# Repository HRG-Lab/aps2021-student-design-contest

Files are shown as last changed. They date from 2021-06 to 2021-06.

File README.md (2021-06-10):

# 2021 IEEE APS/URSI Student Design Contest

This repository contains the Huff Research Group's submission to the [2021 APS Student Design Contest](https://www.ieeeaps.org/education/student-design-contest), Project Artemis. The goal of this project is to demonstrate a software-defined radio (SDR) phased array architecture that performs direction of arrival (DoA) and beamforming (BF). The system will be composed of the KerberosSDR, a 4-channel coherent radio, and use a modified version of the KerberosSDR demo software to perform MUSIC spectral estimation. The focus will be building an educational toolkit that can be utilized to teach beamforming and DoA, comparing analog and digital techniques as well as hybrid analog-digital architectures.

## Motivation and Application

Radio telemetry and direction-finding methods have enabled researchers, practitioners, and citizen scientists in agriculture and biological sciences for decades. These tools are commonly used in data collection on diverse animal populations, such as tracking migratory behavior and monitoring threatened species. Coalescing this data with geotags allows scientists to infer the health of the environment and habitats where these animals reside. Recently, such techniques have been deployed to track the invasive species, _Vespa mandarinia_ (Asian giant hornet) and _Lycorma delicatula_ (spotted lanternfly), and study their impact on native ecosystems. _V. mandarinia_ can rapidly destroy entire honey bee colonies, and _L. delicatula_ can cause huge economic damage to farming and lumber industries.

The goal of Project Artemis is to design and build an extensible invasive species tracking system that utilizes an antenna array with an SDR to perform real-time DoA. Additionally, we view Artemis as a low-cost approach that lowers-the-barrier-to-entry for educators and citizen scientists to engage in the growing fields of antennas, electromagnetics, signal processing, and arrays.

## System Architecture

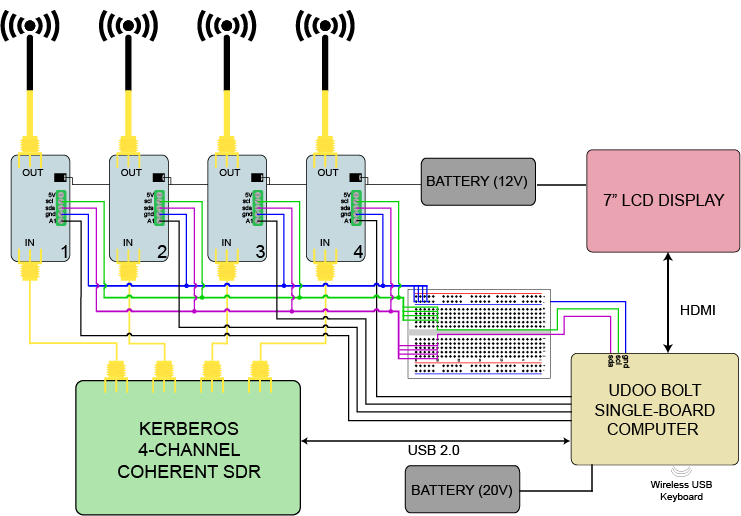
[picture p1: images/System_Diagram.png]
System Diagram


Above is a top-level diagram of Project Artemis detailing the interconnection between various components. The system consists of an easy-to-use software applet built-upon the KerberosSDR  project as well as custom-built, reconfigurable hardware components such as the tunable antenna elements and phase-shifter boards for hybrid beamforming. Towards the intended goal of supporting field-tracking, we have included a small display for real-time visualization and have designed the entire system to be collapsible in a ruggedized suitcase.

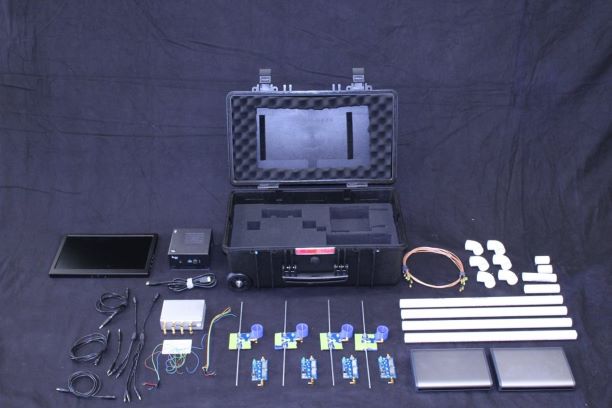
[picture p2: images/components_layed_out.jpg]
Components Layout

 
This shows all of the components to Artemis layed out on a table. This GitHub repository contains all of our design files as well as the source code to Artemis, and the end of this report includes the Bill of Materials. The subsections that follow describe in detail the hardware and software components.

## Artemis Software

The Artemis Software toolkit is a forked version of the KerberosSDR example toolkit, tailored for the purpose of easing usage for end-users.

## Analog Components

Fill in with information on the analog design files.

## Jupyter Teaching Notebooks

Fill in description of Jupyter notebooks to teach array processing.

## References

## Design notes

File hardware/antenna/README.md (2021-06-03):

# Antenna Design

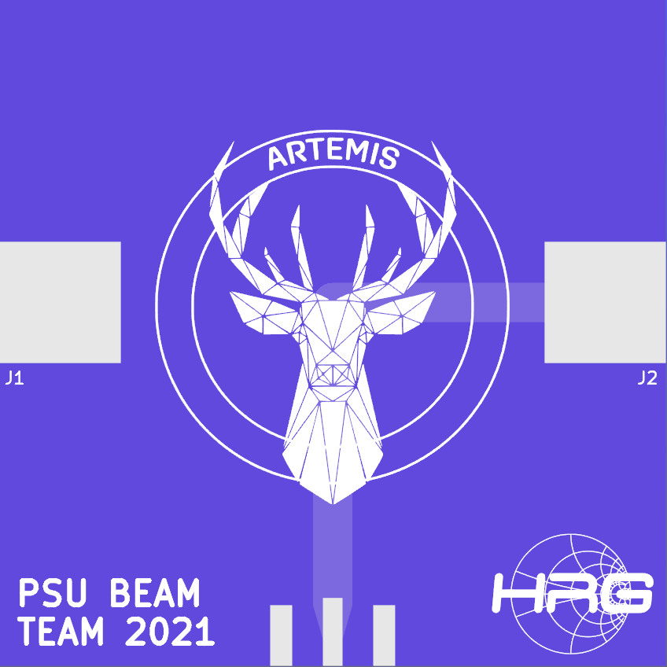
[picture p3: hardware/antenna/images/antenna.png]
Antenna


These are the production files for the antenna. J1 and J2 are each terminal
blocks which hold a conductor (eg. copper wire). When finally assembled, this
creates a dipole antenna.

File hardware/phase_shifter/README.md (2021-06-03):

# Phase Shifter Modules

These modules are designed to be individually addressable fully contained phase
shifters with a full 360 degree range. This folder contains all design files.

## Schematic

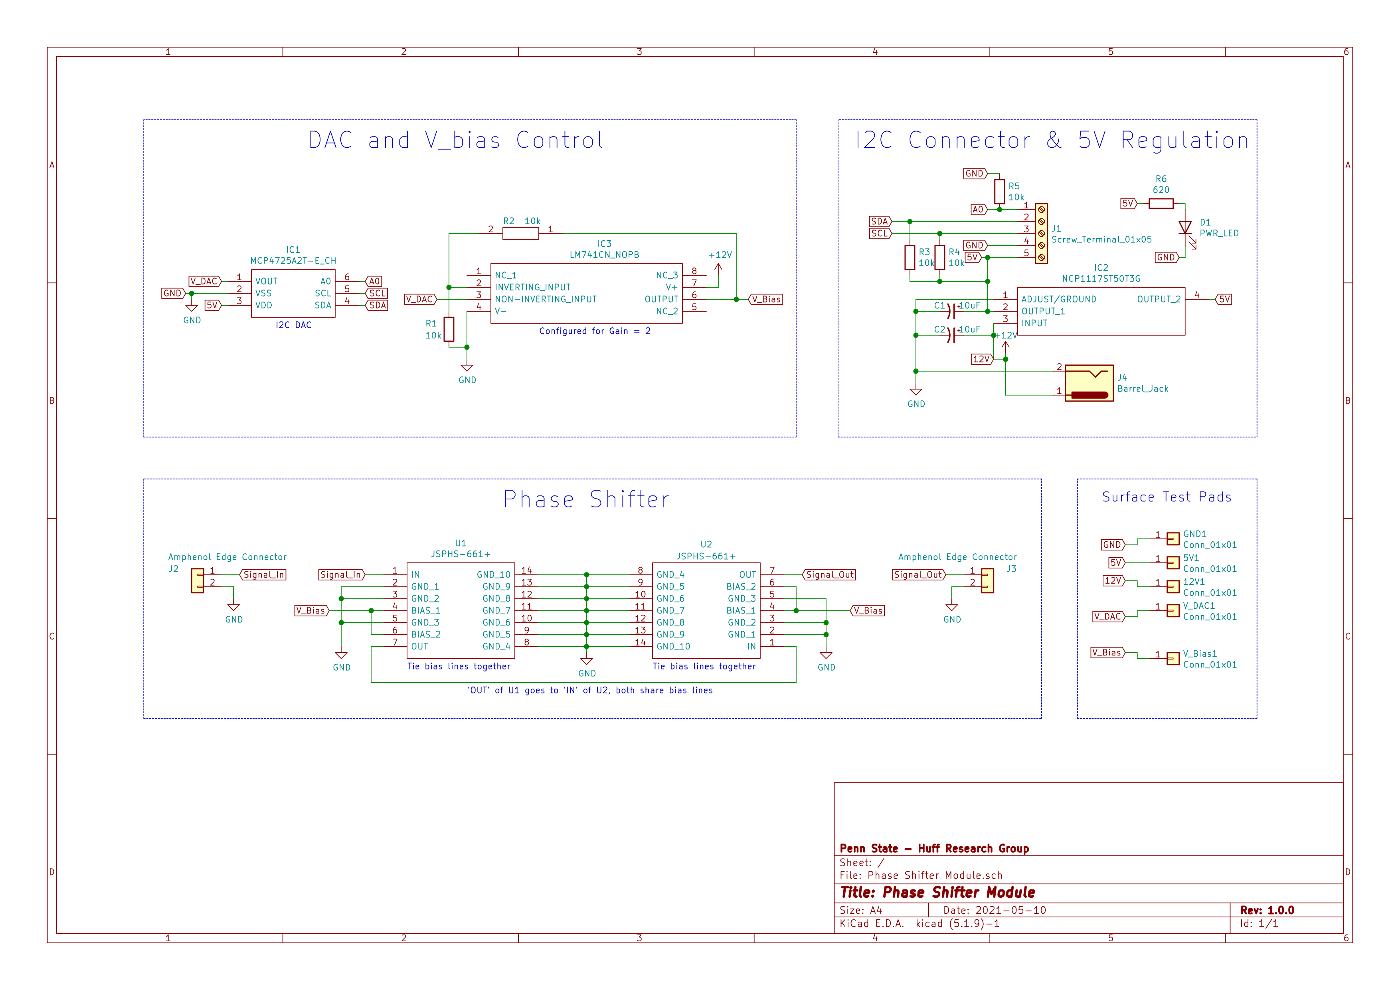
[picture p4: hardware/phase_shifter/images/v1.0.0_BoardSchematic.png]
KiCad Phase Shifter Schematic


## Bill of Materials

| Ref | Value | Footprint |
|---|---|---|
| 5V1 | Conn_01x01 | Phase Shifter Module:TestPad_Medium |
| 12V1 | Conn_01x01 | Phase Shifter Module:TestPad_Medium |
| C1 | 10uF | Capacitor_SMD:C_0805_2012Metric |
| C2 | 10uF | Capacitor_SMD:C_0805_2012Metric |
| D1 | PWR_LED | LED_SMD:LED_0805_2012Metric |
| GND1 | Conn_01x01 | Phase Shifter Module:TestPad_Medium |
| IC1 | MCP4725A2T-E_CH | Package_TO_SOT_SMD:SOT-23-6_Handsoldering |
| IC2 | NCP1117ST50T3G | NCP1117ST50T3G:SOT230P700X180-4N |
| IC3 | LM741CN_NOPB | Package_SO:SOP-8_3.9x4.9mm_P1.27mm |
| J1 | Screw_Terminal_01x05 | TerminalBlock_TE-Connectivity:TerminalBlock_TE_282834-5_1x05_P2.54mm_Horizontal |
| J2 | Amphenol Edge Connector | Amphenol Edge:Amphenol_132255_Edge |
| J3 | Amphenol Edge Connector | Amphenol Edge:Amphenol_132255_Edge |
| J4 | Barrel_Jack | Connector_BarrelJack:BarrelJack_CUI_PJ-063AH_Horizontal |
| R1 | 10k | Resistor_SMD:R_0805_2012Metric |
| R2 | 10k | Resistor_SMD:R_0805_2012Metric |
| R3 | 10k | Resistor_SMD:R_0805_2012Metric |
| R4 | 10k | Resistor_SMD:R_0805_2012Metric |
| R5 | 10k | Resistor_SMD:R_0805_2012Metric |
| R6 | 620 | Resistor_SMD:R_0805_2012Metric |
| U1 | JSPHS-661+ | SamacSys_Parts:JSPHS661 |
| U2 | JSPHS-661+ | SamacSys_Parts:JSPHS661 |
| V_Bias1 | Conn_01x01 | Phase Shifter Module:TestPad_Medium |
| V_DAC1  | Conn_01x01 | Phase Shifter Module:TestPad_Medium |

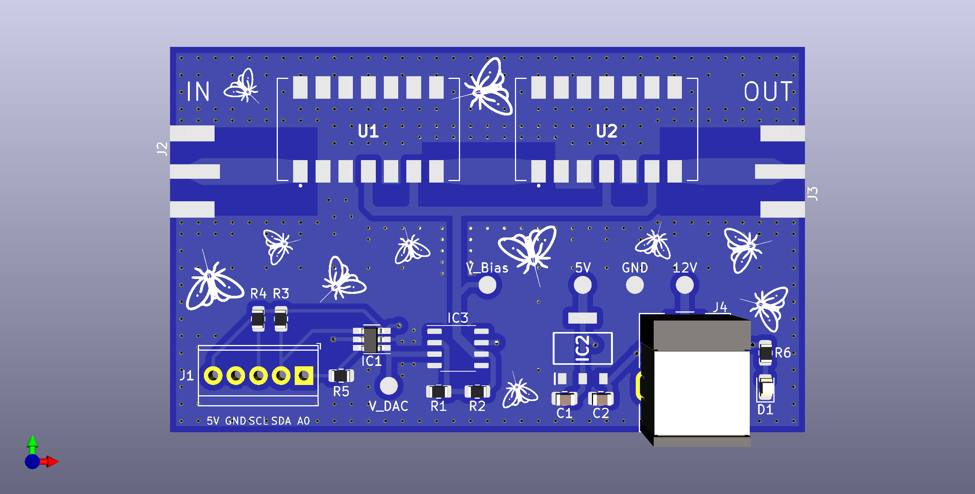
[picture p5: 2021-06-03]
hardware/phase_shifter/images/v1.0.0 3D Layout.png

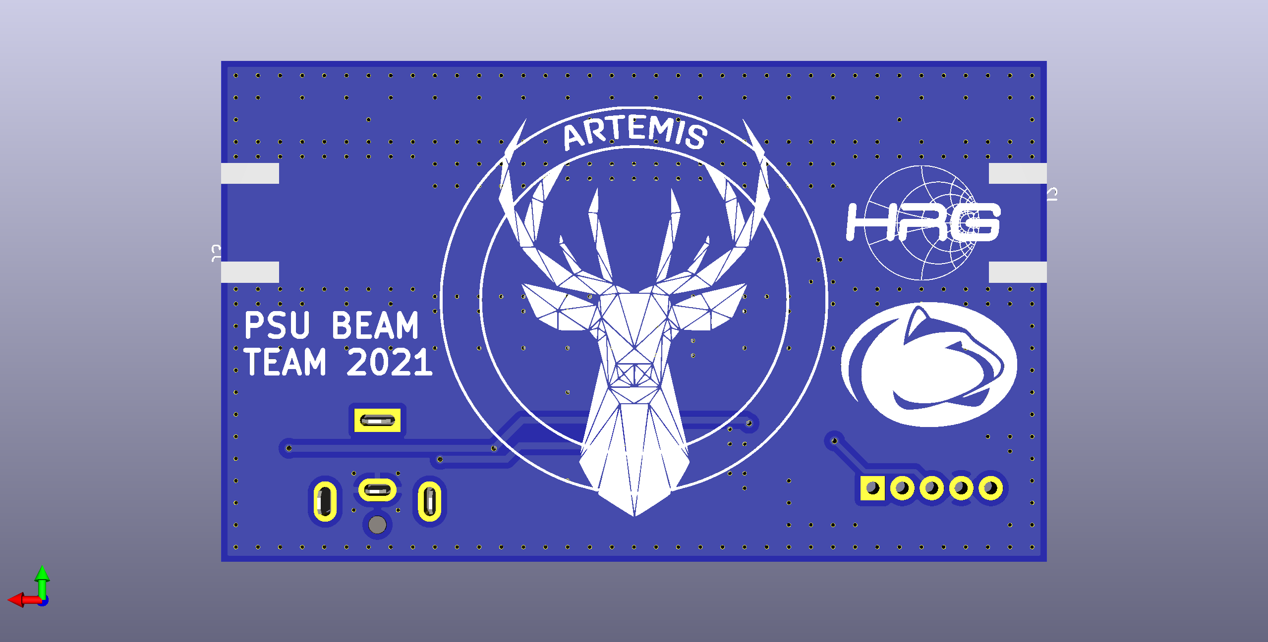
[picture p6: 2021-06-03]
hardware/phase_shifter/images/v1.0.0 3D Layout_Back.png

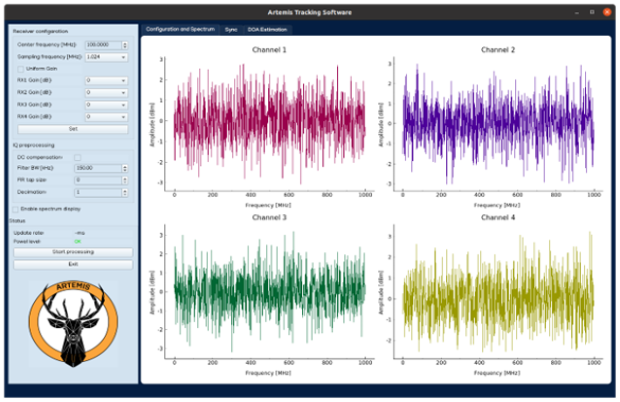
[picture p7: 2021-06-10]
images/Artemis_Spectrum.png

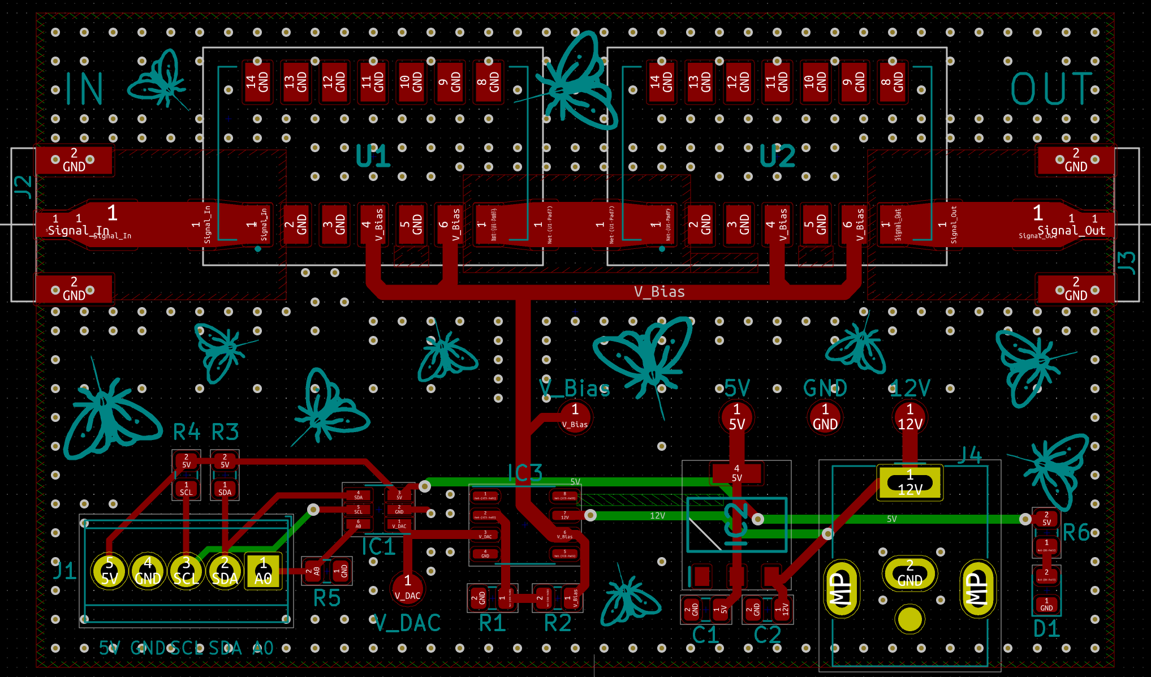
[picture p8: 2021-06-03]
hardware/phase_shifter/images/v1.0.0 Board Layout.png

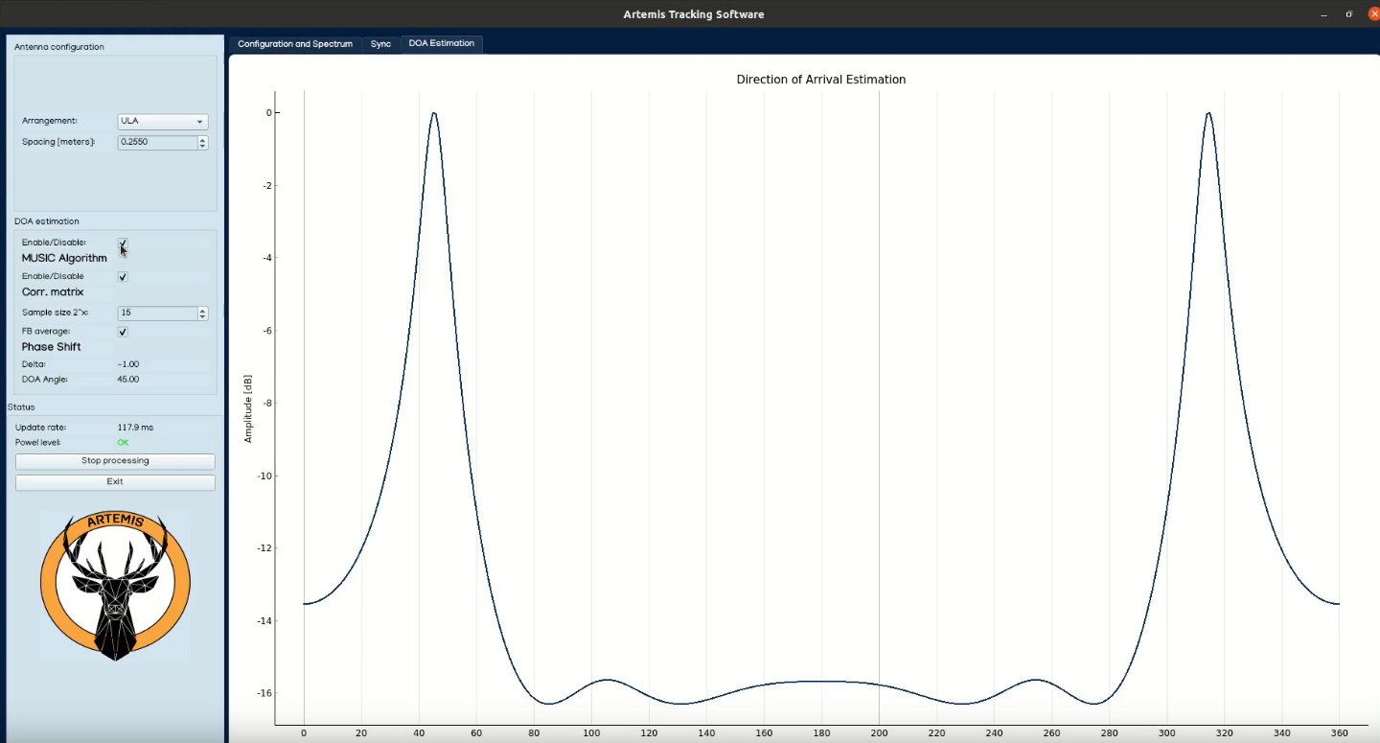
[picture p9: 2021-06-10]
images/hydra_doa.png

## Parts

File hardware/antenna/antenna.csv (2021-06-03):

Source: | /home/gaylybailey/Documents/HRG/sdr-df-bf/aps2021-sdc/aps2021-student-design-contest/hardware/antenna/antenna.sch
Date: | Thu 03 Jun 2021 05:16:01 PM EDT
Tool: | Eeschema 5.1.6+dfsg1-1
Component Count: | 3
Ref | Value | Footprint | Datasheet | Manufacturer | Vendor
J1 | Conn_01x01 | Antenna_Clamp_Adapter:Wire_Clamp | ~
J2 | Conn_01x01 | Antenna_Clamp_Adapter:Wire_Clamp | ~
J3 | Conn_01x02 | Antenna_Clamp_Adapter:Amphenol_132255_Edge | ~

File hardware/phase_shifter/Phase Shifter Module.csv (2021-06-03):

Source: | /home/gaylybailey/Documents/HRG/sdr-df-bf/aps2021-sdc/aps2021-student-design-contest/hardware/phase_shifter/Phase Shifter Module/Phase Shifter Module.sch
Date: | Thu 03 Jun 2021 03:17:47 PM EDT
Tool: | Eeschema 5.1.6+dfsg1-1
Component Count: | 23
Ref | Value | Footprint | Datasheet | Manufacturer | Vendor
5V1 | Conn_01x01 | Phase Shifter Module:TestPad_Medium | ~
12V1 | Conn_01x01 | Phase Shifter Module:TestPad_Medium | ~
C1 | 10uF | Capacitor_SMD:C_0805_2012Metric | ~
C2 | 10uF | Capacitor_SMD:C_0805_2012Metric | ~
D1 | PWR_LED | LED_SMD:LED_0805_2012Metric | ~
GND1 | Conn_01x01 | Phase Shifter Module:TestPad_Medium | ~
IC1 | MCP4725A2T-E_CH | Package_TO_SOT_SMD:SOT-23-6_Handsoldering | http://ww1.microchip.com/downloads/en/devicedoc/22039d.pdf
IC2 | NCP1117ST50T3G | NCP1117ST50T3G:SOT230P700X180-4N | http://www.onsemi.com/pub/Collateral/NCP1117-D.PDF
IC3 | LM741CN_NOPB | Package_SO:SOP-8_3.9x4.9mm_P1.27mm | https://www.ti.com/lit/ds/symlink/lmc6081.pdf?ts=1620626007476
J1 | Screw_Terminal_01x05 | TerminalBlock_TE-Connectivity:TerminalBlock_TE_282834-5_1x05_P2.54mm_Horizontal | ~
J2 | Amphenol Edge Connector | Amphenol Edge:Amphenol_132255_Edge | ~
J3 | Amphenol Edge Connector | Amphenol Edge:Amphenol_132255_Edge | ~
J4 | Barrel_Jack | Connector_BarrelJack:BarrelJack_CUI_PJ-063AH_Horizontal | ~
R1 | 10k | Resistor_SMD:R_0805_2012Metric | ~
R2 | 10k | Resistor_SMD:R_0805_2012Metric | ~
R3 | 10k | Resistor_SMD:R_0805_2012Metric | ~
R4 | 10k | Resistor_SMD:R_0805_2012Metric | ~
R5 | 10k | Resistor_SMD:R_0805_2012Metric | ~
R6 | 620 | Resistor_SMD:R_0805_2012Metric | ~
U1 | JSPHS-661+ | SamacSys_Parts:JSPHS661 | https://www.minicircuits.com/pdfs/JSPHS-661+.pdf
U2 | JSPHS-661+ | SamacSys_Parts:JSPHS661 | https://www.minicircuits.com/pdfs/JSPHS-661+.pdf
V_Bias1 | Conn_01x01 | Phase Shifter Module:TestPad_Medium | ~
V_DAC1 | Conn_01x01 | Phase Shifter Module:TestPad_Medium | ~

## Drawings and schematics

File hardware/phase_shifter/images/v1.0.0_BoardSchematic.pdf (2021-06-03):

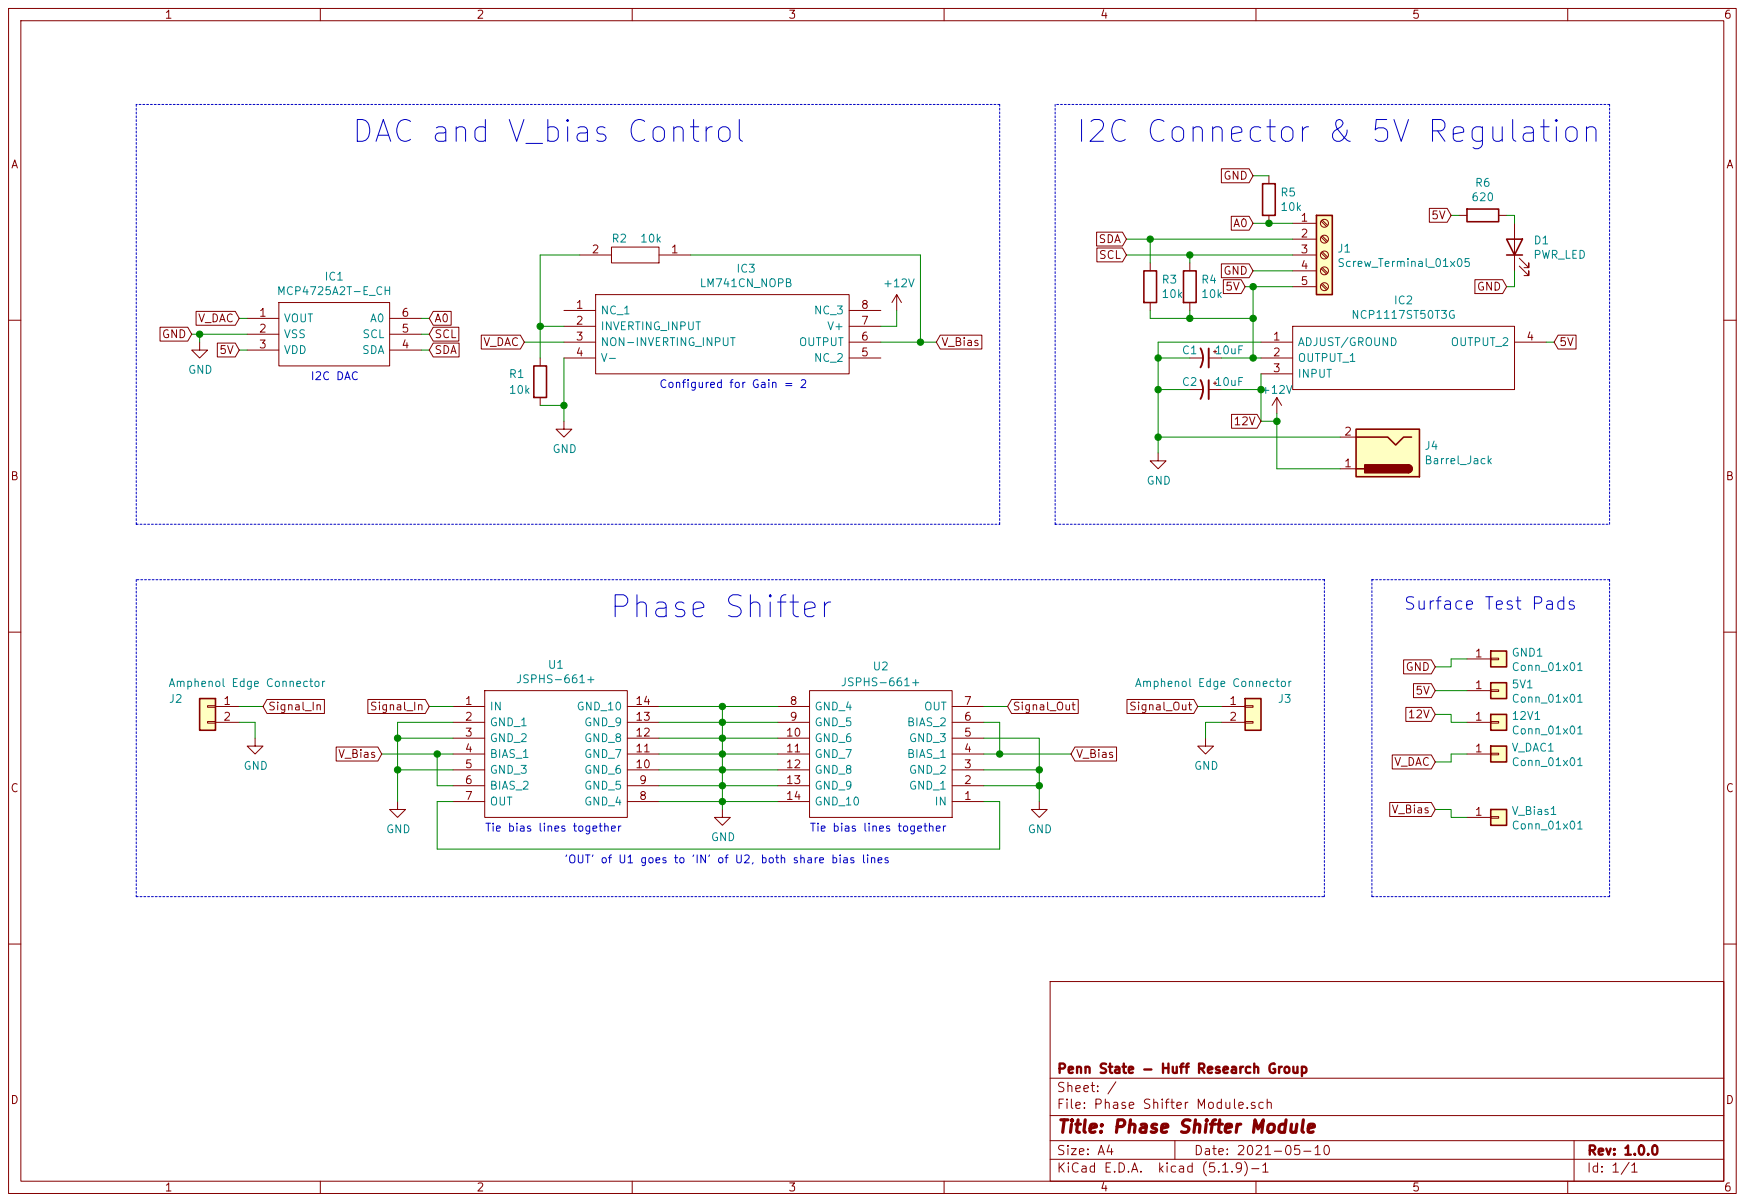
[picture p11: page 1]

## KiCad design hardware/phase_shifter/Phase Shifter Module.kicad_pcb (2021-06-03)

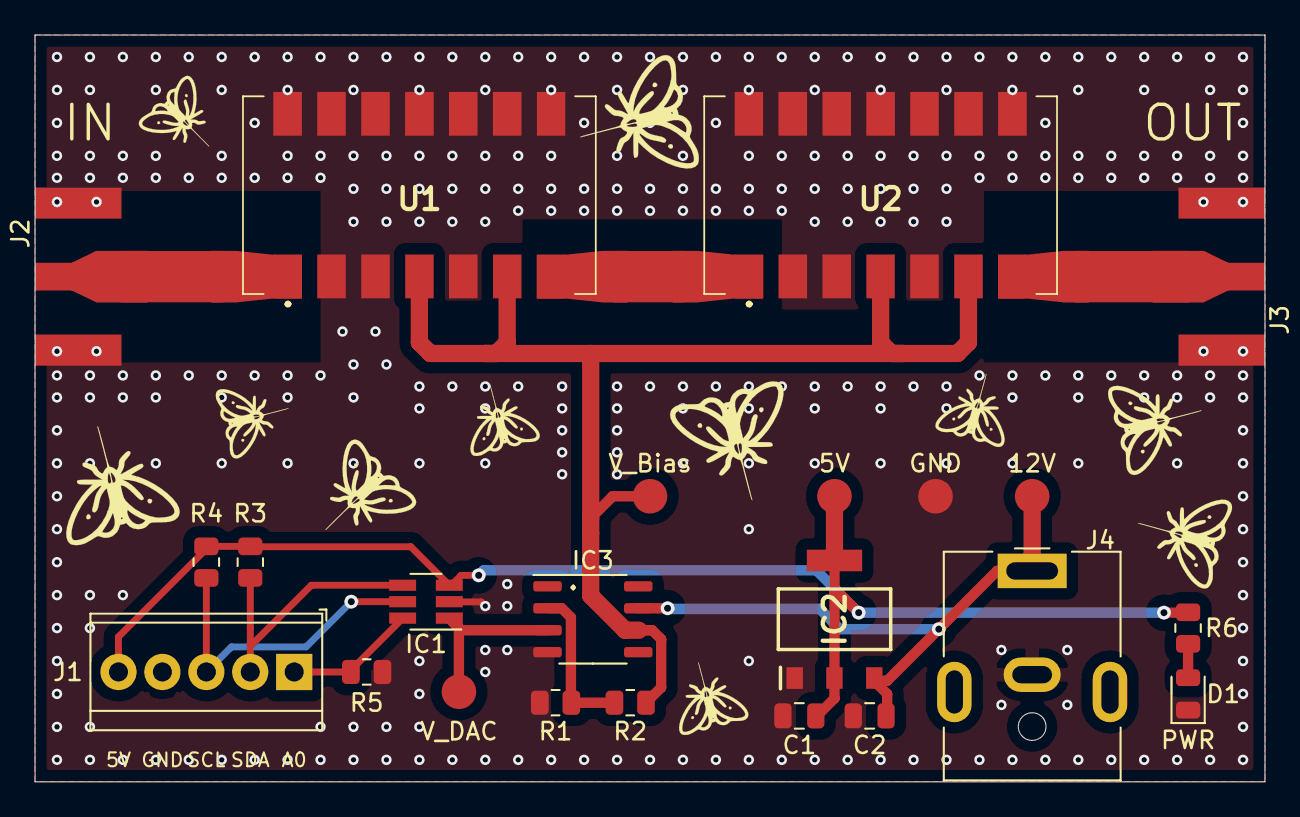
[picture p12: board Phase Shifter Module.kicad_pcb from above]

Board: 2 copper layers, 71.1 x 43.2 mm, 31 parts (0 on the bottom side), 13 nets.

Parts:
5V1, 12V1: Conn_01x01; TestPad_Medium
Artemis: LOGO; Artemis_Logo-Large
C1, C2: 10uF; C_0805_2012Metric
D1: PWR_LED; LED_0805_2012Metric
GND1: Conn_01x01; TestPad_Medium
IC1: MCP4725A2T-E_CH; SOT-23-6_Handsoldering
IC2: NCP1117ST50T3G; SOT230P700X180-4N
IC3: LM741CN_NOPB; SOP-8_3.9x4.9mm_P1.27mm
J1: Screw_Terminal_01x05; TerminalBlock_TE_282834-5_1x05_P2.54mm_Horizontal
J2, J3: Amphenol Edge Connector; Amphenol_132255_Edge
J4: Barrel_Jack; BarrelJack_CUI_PJ-063AH_Horizontal
PSU: LOGO; PSU_Logo
R1, R2, R3, R4, R5: 10k; R_0805_2012Metric
R6: 620; R_0805_2012Metric
Taper: Signal_Pad_to_2.97mm
Taper#2: Signal_Pad_to_2.97mm
Taper#3, Taper#4, Taper#5, Taper#6: 1.5mm_to_2.97mm
U1, U2: JSPHS-661+; JSPHS661
V_Bias1: Conn_01x01; TestPad_Medium
V_DAC1: Conn_01x01; TestPad_Medium

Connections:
5V: 5V1.1, C1.1, IC1.3, IC2.2, IC2.4, J1.5, R3.2, R4.2, R6.2
12V: 12V1.1, C2.1, IC2.3, IC3.7, J4.1
A0: IC1.6, J1.1, R5.2
GND: C1.2, C2.2, D1.1, GND1.1, IC1.2, IC2.1, IC3.4, J1.4, J2.2, J3.2, J4.2, R1.2, R5.1, U1.2, U1.3, U1.5, U1.8, U1.9, U1.10, U1.11, U1.12, U1.13, U1.14, U2.2, U2.3, U2.5, U2.8, U2.9, U2.10, U2.11, U2.12, U2.13, U2.14
unnamed: D1.2, R6.1
unnamed: IC3.2, R1.1, R2.2
unnamed: Taper#5.1, Taper#6.1, U1.7, U2.1
SCL: IC1.5, J1.3, R4.1
SDA: IC1.4, J1.2, R3.1
Signal_In: J2.1, Taper#2.1, Taper#3.1, U1.1
Signal_Out: J3.1, Taper.1, Taper#4.1, U2.7
V_Bias: IC3.6, R2.1, U1.4, U1.6, U2.4, U2.6, V_Bias1.1
V_DAC: IC1.1, IC3.3, V_DAC1.1

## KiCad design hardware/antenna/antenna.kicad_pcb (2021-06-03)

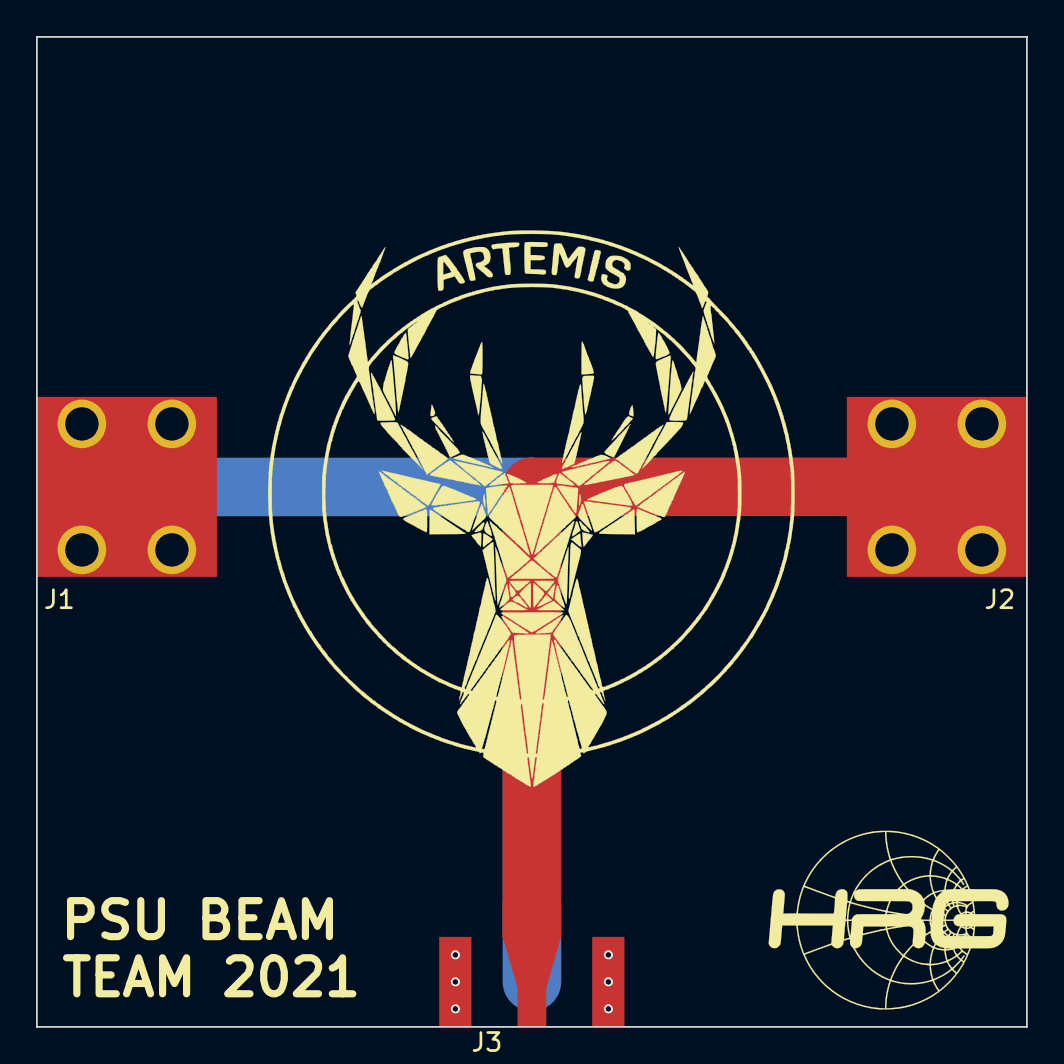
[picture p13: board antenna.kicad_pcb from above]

Board: 2 copper layers, 55.0 x 55.0 mm, 4 parts (0 on the bottom side), 2 nets.

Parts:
J1, J2: Conn_01x01; Wire_Clamp
J3: Conn_01x02; Amphenol_132255_Edge
uwT*****: Signal_Pad_to_3.25mm

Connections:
unnamed: J1.1, J3.2
unnamed: J2.1, J3.1, uwT*****.1

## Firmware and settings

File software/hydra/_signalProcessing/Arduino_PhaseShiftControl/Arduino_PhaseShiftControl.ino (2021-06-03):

/*
  Phase Shifter Module Control Software

  PSU BEAM Team 2021 - Rebecca DeSipio, Mike Shero, Ethan Tabler

  This program requires the Adafruit MCP4725 library to function.
*/

#include <Wire.h>
#include <Adafruit_MCP4725.h>

Adafruit_MCP4725 dac;

void setup() {
  // init digital pins
  pinMode(0, OUTPUT);
  pinMode(1, OUTPUT);
  pinMode(2, OUTPUT);
  pinMode(3, OUTPUT);
  
  // close existing connections before
  Serial.end();

  // initialize serial communication
  Serial.begin(9600);
  Serial.println("Serial connection initialized.");
  
  // This application uses the MCP4725(A2), not the Adafruit breakout board.
  // For the PSM's MCP4725A2 the address is 0x64 (default) or 0x65 (ADDR pin tied to VCC)
  // For MCP4725A0 the address is 0x60 or 0x61
  // For MCP4725A1 the address is 0x62 or 0x63 (Adafruit Breakout Board)
  dac.begin(0x65);

  // initialize A0 control pins and set all LOW
  pinMode(0, OUTPUT);
  pinMode(1, OUTPUT);
  pinMode(2, OUTPUT);
  pinMode(3, OUTPUT);
  for (int i = 0, i <= 3, i++) {
        digitalWrite(i, LOW);
  }
}

void loop() {
  // see if there's incoming serial data
  if (Serial.available() > 0) {
    // look for the next valid integer in the incoming serial stream
    int dacVal = Serial.parseInt();

    // look for the newline --> end of sent value
    if (Serial.read() == '\n') {
     
      //dac.setVoltage((dacVal), false);

      // because there are 4 phase shifters (1 per channel), we must apply
      // the appropriate delta values to each module
      for (int i = 0, i <= 3, i++) {
        // apply delta value --> 0, 1*d, 2*d, 3*d
        digitalWrite(i, HIGH);
        delay(10);
        dac.setVoltage((i*dacVal), false);
        //Serial.println(dacVal);
        delay(10);
        digitalWrite(i, LOW);
      }
      
      dac.setVoltage(dacVal, false);
      Serial.println(dacVal);
     
    }

  }

}

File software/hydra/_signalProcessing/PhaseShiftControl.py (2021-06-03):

# Phase Shifter Module Control Software
#
# PSU BEAM Team 2021 - Rebecca DeSipio, Mike Shero, Ethan Tabler
#
#
#

import serial

# Start a serial connection on port ACM0 with the built-in Arduino Leonardo (Bolt)
# ONLY FOR TESTING - This will be initialized in the hydra_signal_processor file
'''
arduino = serial.Serial('/dev/ttyACM0', 9600, timeout=1)

while True:
    dacVal = int(input("Enter a value between 0 and 4095: "))
    if (dacVal >= 0) and (dacVal <= 4095):
        # Write value to serial port
        arduino.write((str(dacVal) + '\n').encode())

    else:
        print("Please enter a valid number.")
'''


def phaseShift(deltaVal, arduino, side):
    # TODO: Map deltaVal (degrees) to corresponding dacVal (0 to 4095)
    dacVal = 128 * deltaVal

    if side == "l":
        # Write value to serial port
        arduino.write((str(dacVal) + 'l' + '\n').encode())
        
    elif side == "r":
        # Write value to serial port
        arduino.write((str(dacVal) + 'r' + '\n').encode())
